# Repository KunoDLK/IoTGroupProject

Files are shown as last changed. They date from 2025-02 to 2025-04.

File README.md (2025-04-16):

# Project:

## Waste Management Optimization:

Problem: Static bin collection routes can leave many bins overflowing
Solution: Create a smart waste management system with fill-level so the council can optimes bin collection
Sensors: Ultrasonic distance sensors measure bin fill levels; Weight Sensor to approximate waste density; Air Monitoring for potential pollution cause by waste

## Work split:

Kuno:
- Hardware:
  - PCB
  - mounting + assembly
- Firmware:
  - Reading sensors
  - Sending data to cloud
- Creating Fake Data

Mark & Andrea:
- Cloud:
  - Server
- Application:
  - Collecting data from MQTT
  - displaying the data
  - Figure out which bin needs to be collected next

## The data:

- Current Data:
  - Temp
  - humidity
  - Fill Level
  - Weight
  - Density
- Daily Data:
  - Day high Temp
  - Day Low Temp
  - Day Fill delta
- Counters:
  - Time Since Emptied
  - Time Since Full
  - Number of fills
- Server Data
  - trends ect.

## MQTT:

URL:
c79e2ea5e65e40f6b79ba3a3aad7c19f.s1.eu.hivemq.cloud
Port:
8883
Websocket Port:
8884

User:admin
Password:Password1  

## MQTT Websocket Client
https://www.hivemq.com/demos/websocket-client/

## MQTT Data:

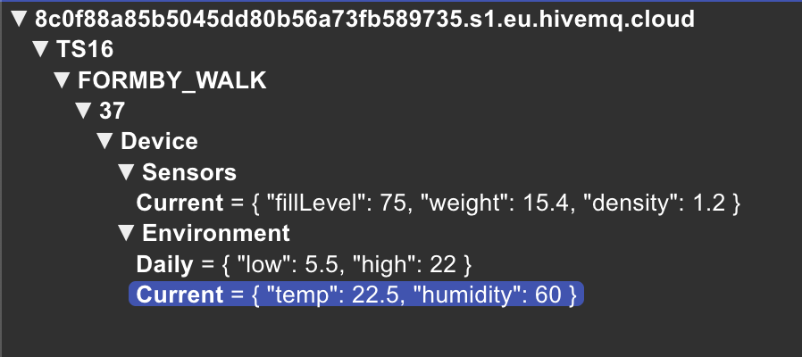
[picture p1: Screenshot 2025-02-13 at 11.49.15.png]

### Data Organisation:
{Postcode area code}/{Street Name}/{House Number}

TS16/FORMBY_WALK/01/

### Sensor Data
./Sensors/Current
{
  "fillLevel": 75,
  "weight": 15.4,
  "density": 1.2
} 

### Environment Data
./Environment/Current
{
  "temp": 22.5,
  "humidity": 60
}

./Environment/Daily
{
  "low": 5.5,
  "high" 22
}

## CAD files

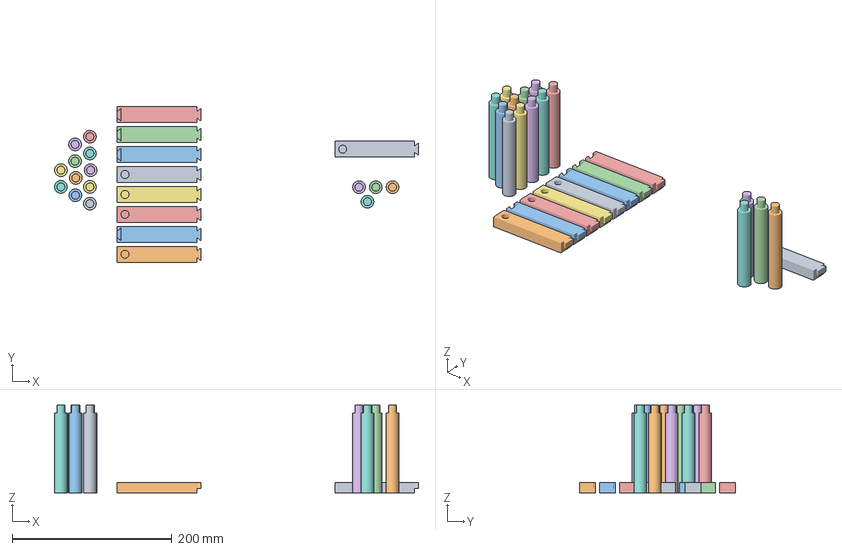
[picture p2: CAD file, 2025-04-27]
Hardware/Suport Beams/parts.3mf
456.4 x 195.0 x 110.0 mm
Straght vertical hole.step x 5
Straght dovetail.step x 4
vertical.step x 15

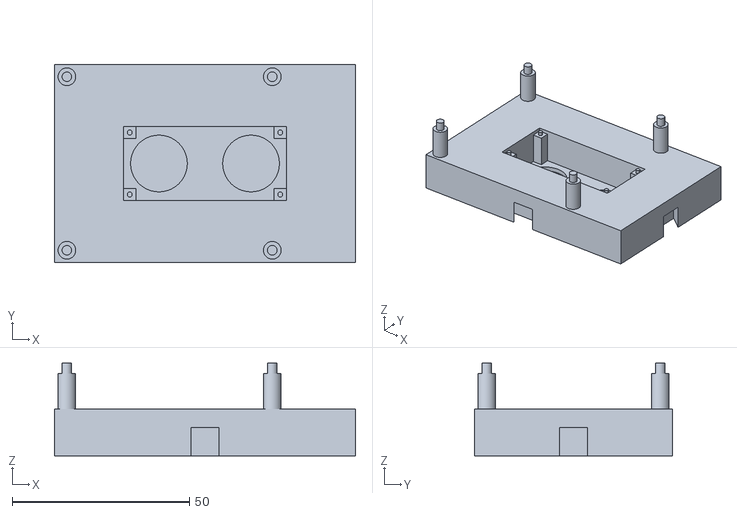
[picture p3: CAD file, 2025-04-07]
Hardware/Top Platform/TopPlatform.stl
85.0 x 56.0 x 26.2

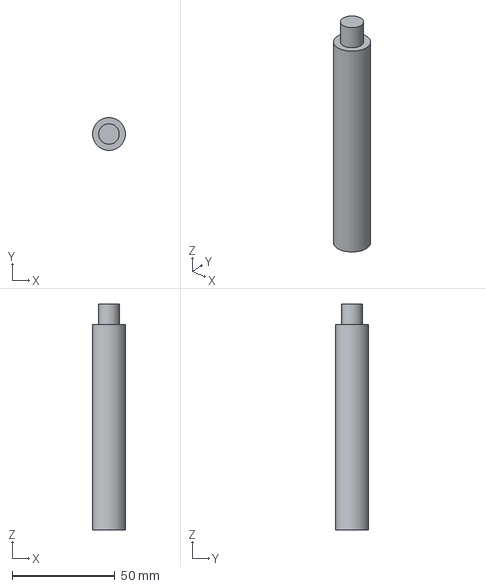
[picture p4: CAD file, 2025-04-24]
Hardware/Suport Beams/vertical.step
16.0 x 16.0 x 110.0 mm

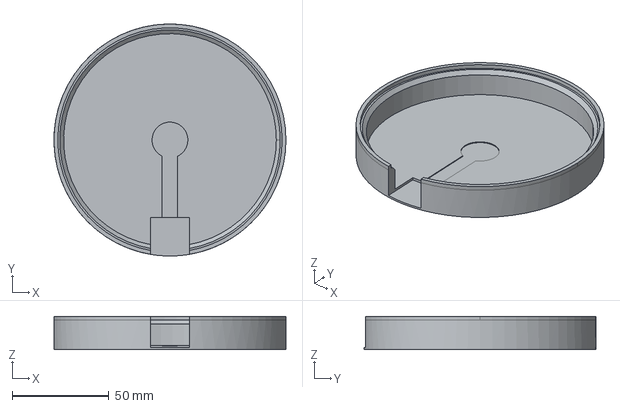
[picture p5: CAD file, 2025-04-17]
Hardware/Weight Platform/base.step
120.0 x 120.0 x 17.2 mm

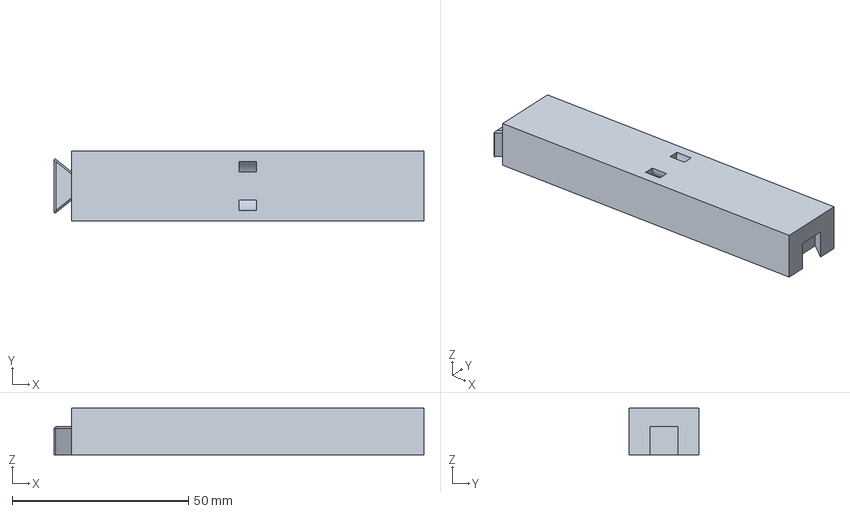
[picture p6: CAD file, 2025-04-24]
Hardware/Suport Beams/Straght.FCStd
105.0 x 20.0 x 13.2 mm

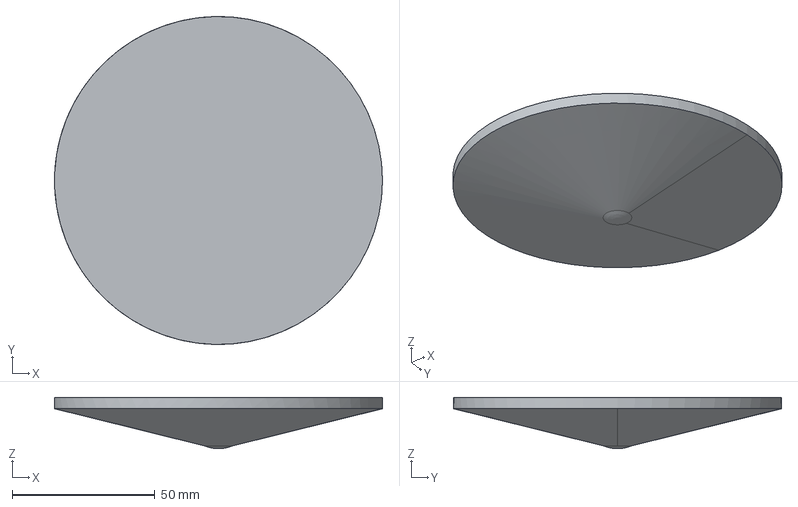
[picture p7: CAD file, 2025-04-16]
Hardware/Weight Platform/platform.step
115.0 x 115.0 x 18.0 mm

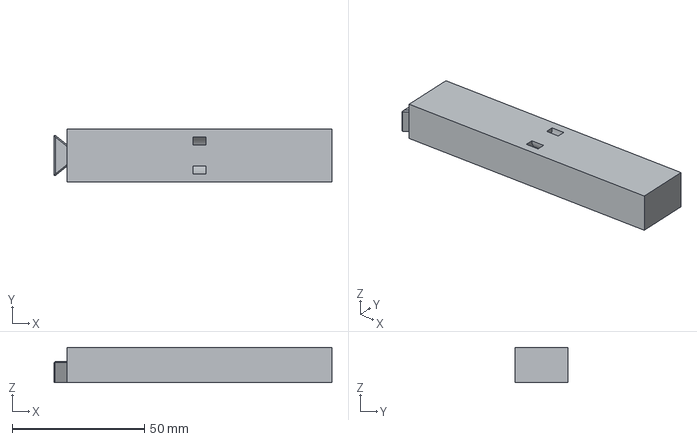
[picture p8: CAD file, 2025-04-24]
Hardware/Suport Beams/Straght vertical hole.step
105.0 x 20.0 x 13.2 mm

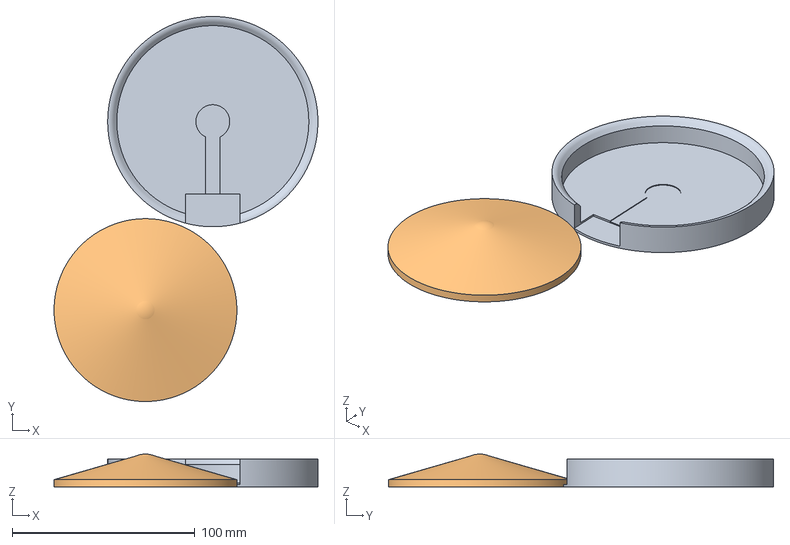
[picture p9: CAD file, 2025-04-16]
Hardware/Weight Platform/print.3mf
144.3 x 210.6 x 18.0 mm
base.step
platform.step

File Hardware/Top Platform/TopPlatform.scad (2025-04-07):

$fn = $preview ? 50 : 500;

PCB_Width = 46.0;
PCB_Depth = 1.2;
PCB_Height = 21.0;
PCB_Sonic_Height = 12.01;
PCB_Sonic_Radius = 8.0;
PCB_Sonic_Offset = 13.0;
PCB_Hole_Radius = 0.7;
PCB_Hole_X_Offset = 21.25;
PCB_Hole_Y_Offset = 8.75;

Sonic_Support_Depth = 1.5;

PI_Height = 85;
PI_Width = 56;
PI_Support_Height = 10;
PI_Support_Width = 5;
PI_Support_Offset_Y = 24.5;
PI_Support_X_Offset_1 = 19;
PI_Support_X_Offset_2 = 39;

Joint_dove_height = 8;
Joint_dove_depth = 5;
Joint_dove_rear_width = 16;
Joint_dove_front_width = 8;

showPI = false;
splitView = false;


if (splitView)
{
    intersection()
    {
        Viewer();
        
        translate([-PI_Height/2,0,0]) cube([PI_Height, PI_Width, PCB_Sonic_Height + PCB_Depth + PI_Support_Height + 3]);
    }
}
else
{
    Viewer();
}

module Viewer()
{
    if (showPI)
    {
        translate([0,0,PI_Support_Height + PCB_Depth + PCB_Sonic_Height]) RPi();
    }

    Main();
}


module Main()
{
    union()
    {
        difference()
        {
            color("Yellow") Base();
        
            rotate([180,0,0]) 
            {
                translate([0,0,-PCB_Depth - PCB_Sonic_Height]) 
                {
                    color("Red") Utrasonic();
                    color("blue")
                    {
                        cutoutLengthWidth = PCB_Height - (4 * ((PCB_Height / 2) - (PCB_Hole_Y_Offset)));
                        cutoutWidthLength = PCB_Width - (4 * ((PCB_Width / 2) - (PCB_Hole_X_Offset)));
                        
                        linear_extrude(PCB_Depth + PCB_Sonic_Height - Sonic_Support_Depth) union()
                        {
                            square([PCB_Width,cutoutLengthWidth], center = true);
                            square([cutoutWidthLength, PCB_Height], center = true);
                        }
                    }
                }
                
            }
        }
        
        translate([PI_Support_X_Offset_1,PI_Support_Offset_Y,PCB_Depth + PCB_Sonic_Height]) Support();
        translate([-PI_Support_X_Offset_2,PI_Support_Offset_Y,PCB_Depth + PCB_Sonic_Height]) Support();
        translate([PI_Support_X_Offset_1,-PI_Support_Offset_Y,PCB_Depth + PCB_Sonic_Height]) Support();
        translate([-PI_Support_X_Offset_2,-PI_Support_Offset_Y,PCB_Depth + PCB_Sonic_Height]) Support();
    }
}

module Base()
{
    render()
    {
        difference()
        {
            linear_extrude(PCB_Depth + PCB_Sonic_Height)
            {
                square([PI_Height,PI_Width], center = true);
            }
            
            linear_extrude(Joint_dove_height)
            {
                union()
                {
                    rotate([0,0,0]) translate([0, -PI_Width / 2,0]) Dovetail2d();
                    rotate([0,0,90]) translate([0, -PI_Height / 2,0]) Dovetail2d();
                    rotate([0,0,180]) translate([0, -PI_Width / 2,0]) Dovetail2d();
                    rotate([0,0,270]) translate([0, -PI_Height / 2,0]) Dovetail2d();
                }
            }
        }
    }
}

module Dovetail2d()
{
    frontOffset = Joint_dove_front_width / 2;
    rearOffset = Joint_dove_rear_width / 2;
                
    polygon([[-frontOffset,0],
    [frontOffset,0],
    [rearOffset, Joint_dove_depth],
    [-rearOffset, Joint_dove_depth]]);
}

module RPi()
{
    difference()
    {
        
        linear_extrude(1.4)
            square([PI_Height, PI_Width], center = true); 
    
        translate([-(PI_Height / 2) + 3.5,-(PI_Width / 2) + 3.5,0])
        {
            Hole();
            translate([58, 0 ,0])
            {
                Hole();
            }
        }
        translate([-(PI_Height / 2) + 3.5,+(PI_Width / 2) - 3.5,0])
        {
            Hole();
            translate([58, 0 ,0])
            {
                Hole();
            }
        }
    }
}

module Hole()
{
    cylinder(h = 3, r = 2.7 / 2);
}
   
module Support()
{
    cylinder(h =PI_Support_Height, r = PI_Support_Width / 2);
    translate([0,0,PI_Support_Height])
    {
        Hole();
    }
}

module Utrasonic() {
    
    difference()
    {
        
        union() {
            translate([-(PCB_Width / 2), -(PCB_Height / 2), 0])
            {
                cube([PCB_Width, PCB_Height, PCB_Depth]);
            }
            translate([PCB_Sonic_Offset, 0, PCB_Depth])
            {
                cylinder(h = PCB_Sonic_Height, r = PCB_Sonic_Radius);
            }
            translate([-PCB_Sonic_Offset, 0, PCB_Depth])
            {
                cylinder(h = PCB_Sonic_Height, r = PCB_Sonic_Radius);
            }
        }
        translate([PCB_Hole_X_Offset, PCB_Hole_Y_Offset, -1])
        {
            cylinder(h = PCB_Depth + 2, r = PCB_Hole_Radius);
        }
        translate([-PCB_Hole_X_Offset, PCB_Hole_Y_Offset, -1])
        {
            cylinder(h = PCB_Depth + 2, r = PCB_Hole_Radius);
        }
        translate([PCB_Hole_X_Offset, -PCB_Hole_Y_Offset, -1])
        {
            cylinder(h = PCB_Depth + 2, r = PCB_Hole_Radius);
        }
        translate([-PCB_Hole_X_Offset, -PCB_Hole_Y_Offset, -1])
        {
            cylinder(h = PCB_Depth + 2, r = PCB_Hole_Radius);
        }
    }
}

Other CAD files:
Hardware/Weight Platform/assembly.FCStd
Hardware/Suport Beams/Straght dovetail.step
Hardware/Suport Beams/Straght vertical hole.FCStd
Hardware/Suport Beams/Vertical.FCStd
Hardware/Weight Platform/base.FCStd
Hardware/Weight Platform/platform.FCStd

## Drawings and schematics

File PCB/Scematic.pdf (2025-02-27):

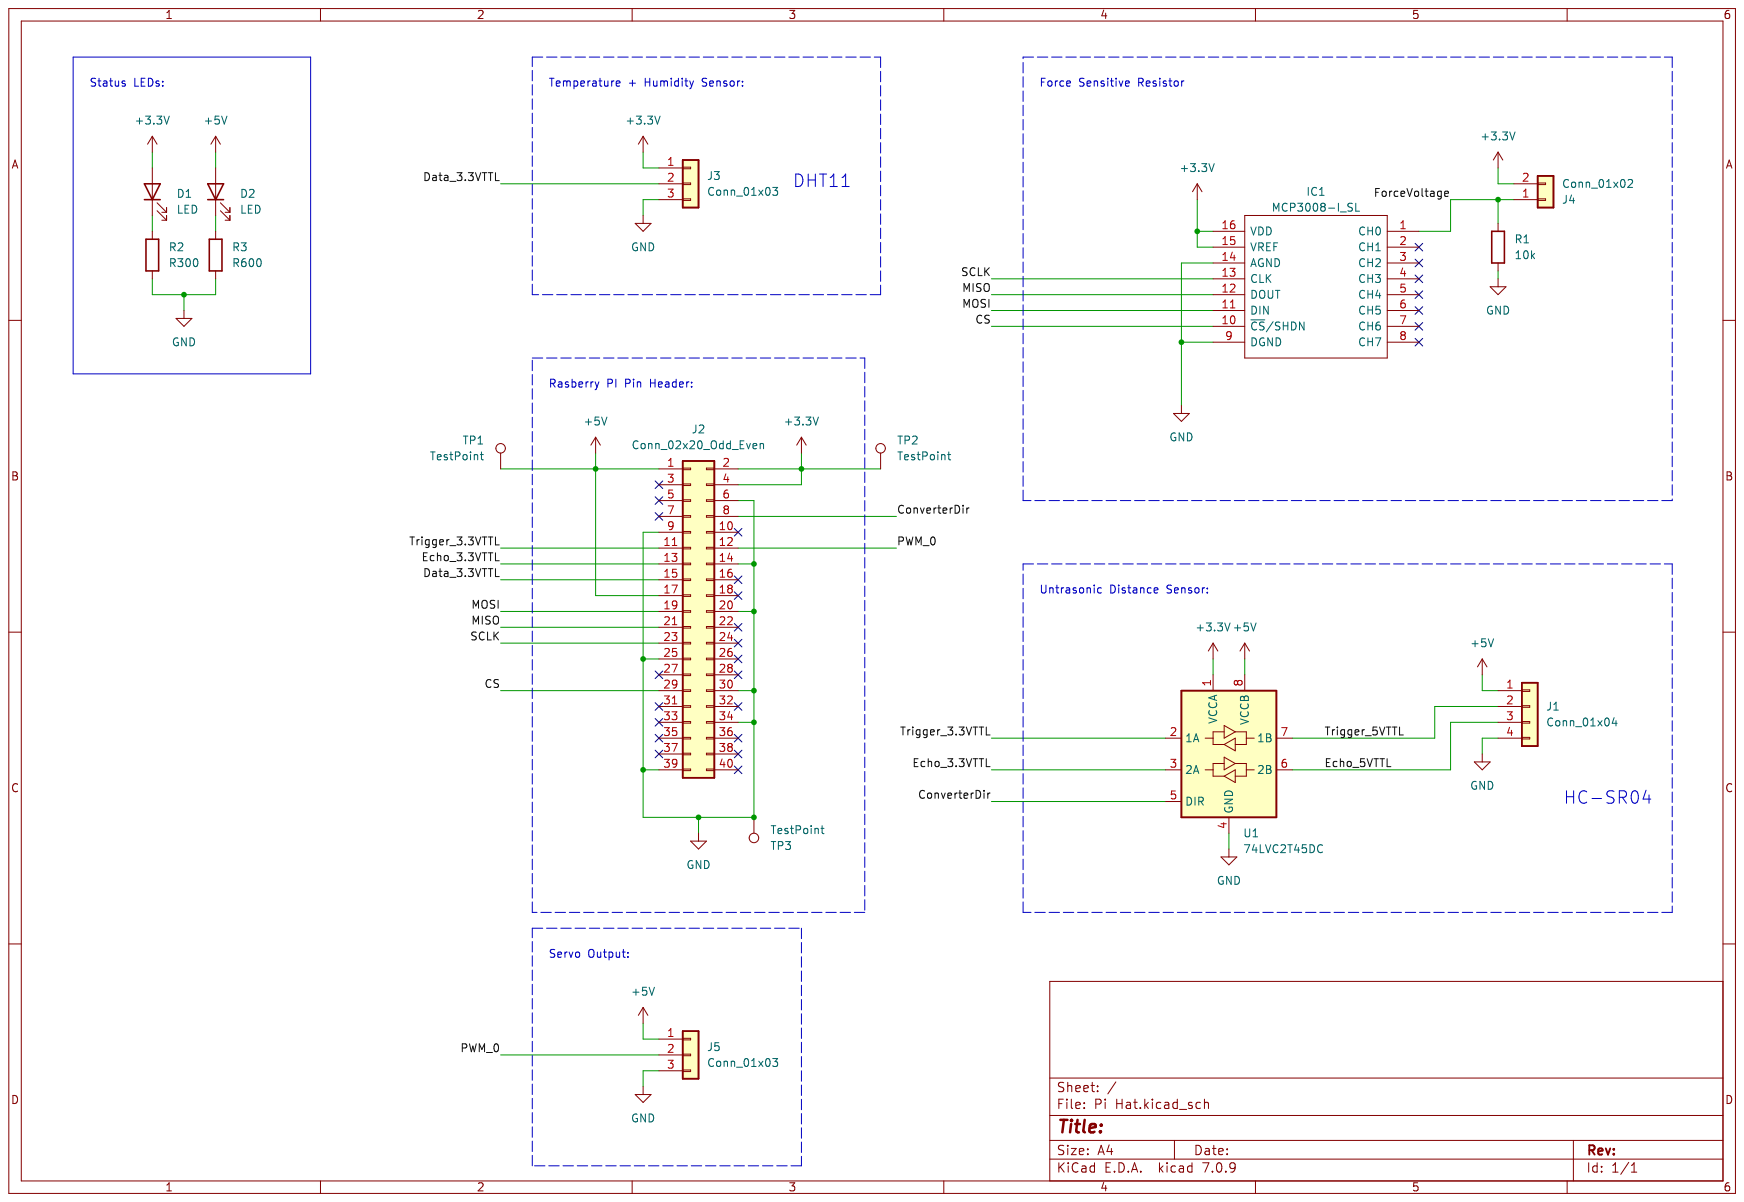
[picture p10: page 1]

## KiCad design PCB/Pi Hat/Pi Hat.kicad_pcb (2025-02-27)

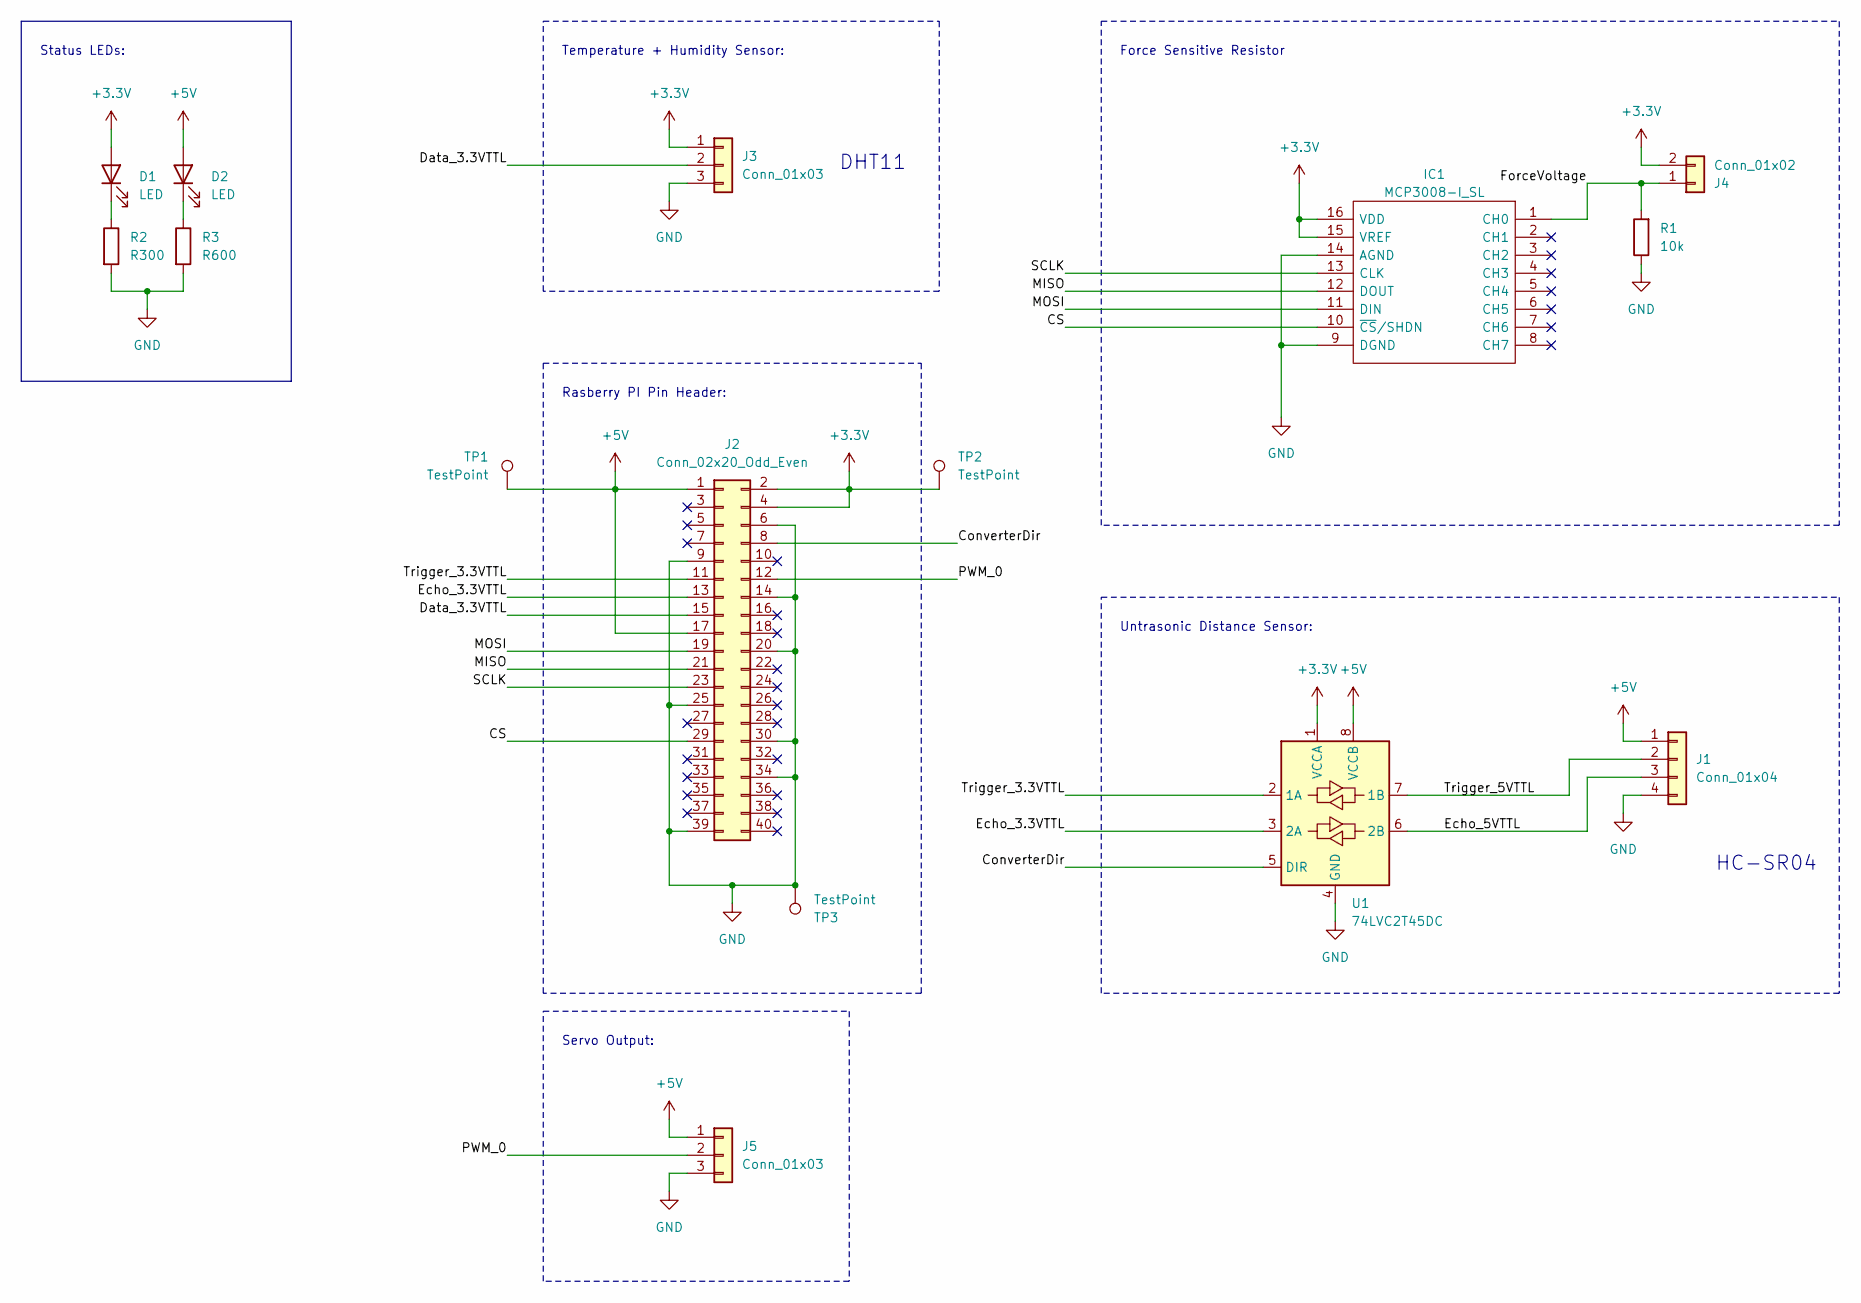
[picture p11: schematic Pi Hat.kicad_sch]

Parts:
D1, D2: LED; LED_0805_2012Metric
IC1: MCP3008-I_SL; DIP-16_W7.62mm_Socket; Manufacturer_Part_Number MCP3008-I/SL; Mouser Part Number 579-MCP3008-I/SL
J1: Conn_01x04; Molex_KK-254_AE-6410-04A_1x04_P2.54mm_Vertical
J2: Conn_02x20_Odd_Even; PinSocket_2x20_P2.54mm_Vertical
J3, J5: Conn_01x03; Molex_KK-254_AE-6410-03A_1x03_P2.54mm_Vertical
J4: Conn_01x02; Molex_KK-254_AE-6410-02A_1x02_P2.54mm_Vertical
R1: 10k; R_0805_2012Metric
R2: R300; R_0805_2012Metric
R3: R600; R_0805_2012Metric
TP1, TP2, TP3: TestPoint; TestPoint_Pad_D3.0mm
U1: 74LVC2T45DC; VSSOP-8_2.3x2mm_P0.5mm

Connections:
+3.3V: D1.2 (A), IC1.15 (VREF), IC1.16 (VDD), J2.2, J2.4, J3.1, J4.2, TP2.1, U1.1 (VCCA)
+5V: D2.2 (A), J1.1, J2.1, J2.17, J5.1, TP1.1, U1.8 (VCCB)
/CS: IC1.10 (~CS/SHDN), J2.29
/ConverterDir: J2.8, U1.5 (DIR)
/Data_3.3VTTL: J2.15, J3.2
/Echo_3.3VTTL: J2.13, U1.3 (2A)
/Echo_5VTTL: J1.3, U1.6 (2B)
/ForceVoltage: IC1.1 (CH0), J4.1, R1.2
/MISO: IC1.12 (DOUT), J2.21
/MOSI: IC1.11 (DIN), J2.19
/PWM_0: J2.12, J5.2
/SCLK: IC1.13 (CLK), J2.23
/Trigger_3.3VTTL: J2.11, U1.2 (1A)
/Trigger_5VTTL: J1.2, U1.7 (1B)
GND: IC1.9 (DGND), IC1.14 (AGND), J1.4, J2.6, J2.9, J2.14, J2.20, J2.25, J2.30, J2.34, J2.39, J3.3, J5.3, R1.1, R2.2, R3.2, TP3.1, U1.4 (GND)
unnamed: D1.1 (K), R2.1
unnamed: D2.1 (K), R3.1

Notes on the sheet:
Untrasonic Distance Sensor:
Servo Output:
Force Sensitive Resistor
Status LEDs:
DHT11
Temperature + Humidity Sensor:
Rasberry PI Pin Header:
HC-SR04

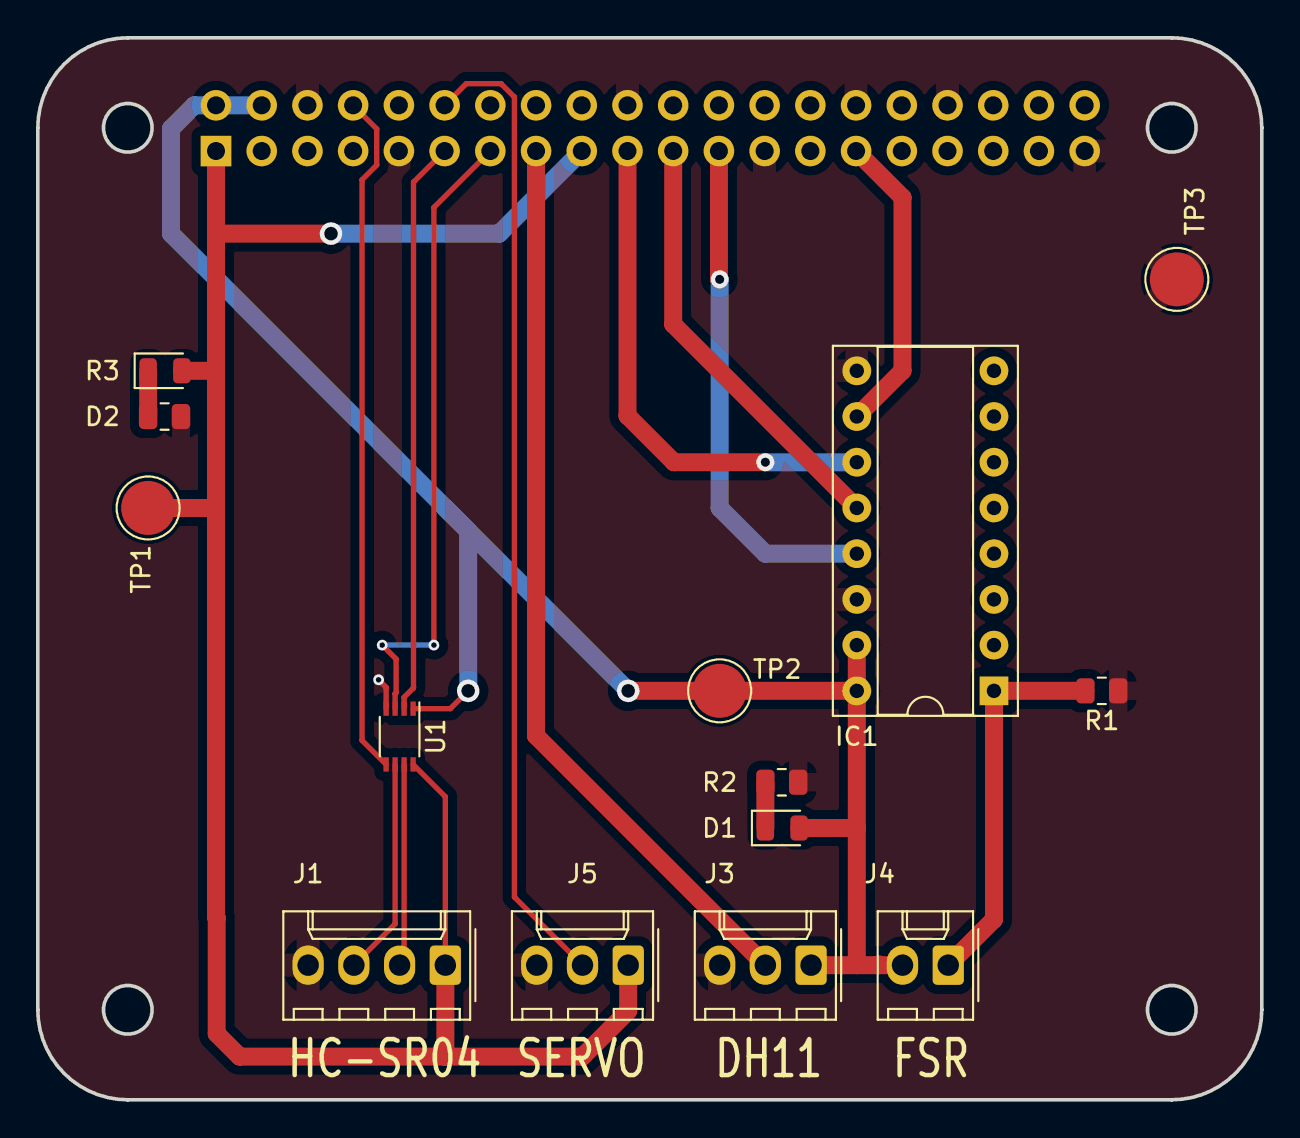
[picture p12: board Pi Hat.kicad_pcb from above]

Board: 2 copper layers, 68.0 x 59.0 mm, 15 parts (1 on the bottom side), 17 nets.

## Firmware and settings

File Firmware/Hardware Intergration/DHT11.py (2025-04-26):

#!/usr/bin/env python
# -*- coding: utf-8 -*-

from __future__ import absolute_import, division, print_function, unicode_literals

import time
import pigpio


class DHT11(object):
    """
    The DHT11 class is a stripped version of the DHT22 sensor code by joan2937.
    """

    def __init__(self, pi, gpio):
        """
        pi (pigpio): an instance of pigpio
        gpio (int): gpio pin number
        """
        self.pi = pi
        self.gpio = gpio
        self.high_tick = 0
        self.bit = 40
        self.temperature = 0
        self.humidity = 0
        self.either_edge_cb = None
        self.setup()

    def setup(self):
        """
        Clears the internal gpio pull-up/down resistor.
        Kills any watchdogs.
        """
        self.pi.set_pull_up_down(self.gpio, pigpio.PUD_OFF)
        self.pi.set_watchdog(self.gpio, 0)
        self.register_callbacks()

    def register_callbacks(self):
        """
        Monitors RISING_EDGE changes using callback.
        """
        self.either_edge_cb = self.pi.callback(
            self.gpio,
            pigpio.EITHER_EDGE,
            self.either_edge_callback
        )

    def either_edge_callback(self, gpio, level, tick):
        """
        Either Edge callbacks, called each time the gpio edge changes.
        Accumulate the 40 data bits from the dht11 sensor.
        """
        level_handlers = {
            pigpio.FALLING_EDGE: self._edge_FALL,
            pigpio.RISING_EDGE: self._edge_RISE,
            pigpio.EITHER_EDGE: self._edge_EITHER
        }
        handler = level_handlers[level]
        diff = pigpio.tickDiff(self.high_tick, tick)
        handler(tick, diff)

    def _edge_RISE(self, tick, diff):
        """
        Handle Rise signal.
        """
        val = 0
        if diff >= 50:
            val = 1
        if diff >= 200:  # Bad bit?
            self.checksum = 256  # Force bad checksum

        if self.bit >= 40:  # Message complete
            self.bit = 40
        elif self.bit >= 32:  # In checksum byte
            self.checksum = (self.checksum << 1) + val
            if self.bit == 39:
                # 40th bit received
                self.pi.set_watchdog(self.gpio, 0)
                total = self.humidity + self.temperature
                # Is checksum ok?
        elif 16 <= self.bit < 24:  # In temperature byte
            self.temperature = (self.temperature << 1) + val
        elif 0 <= self.bit < 8:  # In humidity byte
            self.humidity = (self.humidity << 1) + val
        else:
            pass  # Skip header bits
        self.bit += 1

    def _edge_FALL(self, tick, diff):
        """
        Handle Fall signal.
        """
        self.high_tick = tick
        if diff <= 250000:
            return
        # Start of new message
        self.bit = -2
        self.checksum = 0
        self.temperature = 0
        self.humidity = 0

    def _edge_EITHER(self, tick, diff):
        """
        Handle Either signal.
        """
        self.pi.set_watchdog(self.gpio, 0)

    def read(self):
        """
        Start reading over DHT11 sensor.
        """
        self.pi.write(self.gpio, pigpio.LOW)
        time.sleep(0.017)  # 17 ms
        self.pi.set_mode(self.gpio, pigpio.INPUT)
        self.pi.set_watchdog(self.gpio, 200)
        time.sleep(0.2)

    def close(self):
        """
        Stop reading sensor, remove callbacks.
        """
        self.pi.set_watchdog(self.gpio, 0)
        if self.either_edge_cb:
            self.either_edge_cb.cancel()
            self.either_edge_cb = None

    def __iter__(self):
        """
        Support the iterator protocol.
        """
        return self

    def __next__(self):
        """
        Call the read method and return temperature and humidity information.
        """
        self.read()
        response = {
            'humidity': self.humidity,
            'temperature': self.temperature
        }
        return response

    # For Python 2 compatibility (optional)
    next = __next__


# --- Test code ---

if __name__ == "__main__":
    pi = pigpio.pi()
    
    if not pi.connected:
        print("Failed to connect to pigpio daemon!")
    else:
        try:
            sensor = DHT11(pi, 4)  # GPIO4
            
            while True:
                d = next(sensor)   # Use next() explicitly or use a for loop with iter(sensor)
                print("Temperature: {}°C".format(d['temperature']))
                print("Humidity: {}%".format(d['humidity']))
                time.sleep(1)
                
        
        except KeyboardInterrupt:
            print("\nProgram stopped by user.")
        
        finally:
            sensor.close()
            pi.stop()

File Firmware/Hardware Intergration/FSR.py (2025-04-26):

import spidev

class ADCReader:
    def __init__(self, bus=0, device=0, speed=1350000):
        self.spi = spidev.SpiDev()
        self.spi.open(bus, device)
        self.spi.max_speed_hz = speed

    def read_channel(self, channel):
        if not 0 <= channel <= 7:
            return -1
        adc = self.spi.xfer2([1, (8 + channel) << 4, 0])
        value = ((adc[1] & 3) << 8) + adc[2]
        return value

    def close(self):
        self.spi.close()


import time
import math

weightReader = ADCReader()
lastPrintedWeight = -100.0
lastPrintTime = time.time()

try:
    while True:
        adc_value = weightReader.read_channel(0)
        voltage = (adc_value / 1024.0) * 5.0  # Convert ADC count to voltage
        weight =  0.2 * math.exp(voltage)   # Since a=1 and b=1, F = e^(V)

        currentTime = time.time()
        
        if abs(weight - lastPrintedWeight) > 1:
            print("Weight: {:.2f}KG".format(weight))
            lastPrintedWeight = weight
            lastPrintTime = currentTime
        elif currentTime - lastPrintTime >= 0.5:
            print("Weight: {:.2f}KG".format(weight))
            lastPrintedWeight = weight
            lastPrintTime = currentTime

        time.sleep(0.05)  # 10ms

except KeyboardInterrupt:
    print("\nProgram stopped by user.")

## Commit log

2025-01-30 Added example code for temp/humid Sensor DH11
2025-01-30 Added PI Hat PCB
    [Pi Hat.kicad_pcb, Pi Hat.kicad_sch]
2025-01-30 completed PCB
    [Pi Hat.kicad_pcb, Pi Hat.kicad_sch]
2025-01-30 Experted fabrication files
    [Pi Hat-B_Cu.gbr, Pi Hat-B_Mask.gbr, Pi Hat-B_Silkscreen.gbr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]
2025-01-30 updated PCB
    [Pi Hat.kicad_pcb]
2025-02-03 added 3d design files
    [BinPOC.scad, BinPOC.stl]
2025-02-03 completed placement of ultrasonic sensor
    [BinPOC.scad]
2025-02-04 completed mounting for PI
    [BinPOC.scad, BinPOC.stl]
2025-02-27 complete PCB
    [BinPOC.scad, BinPOC.stl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]
2025-02-27 DFM check adjustments
    [Pi Hat-B_Cu.gbr, Pi Hat-B_Mask.gbr, Pi Hat-B_Silkscreen.gbr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]
2025-04-03 restructured binPOC model. smaller platform with dovetail joints
    [BinPOC.scad]
2025-04-03 Updated model
    [BinPOC.stl]
2025-04-03 adjusted dovetail joints for strength
    [BinPOC.scad, BinPOC.stl]
2025-04-06 made adjustments to pi holder for better sonic fitment
    [BinPOC.scad]
2025-04-06 exported binPOC stl
    [BinPOC.stl]
2025-04-06 changed file name
    [TopPlatform.scad, TopPlatform.stl]
2025-04-06 renamed top platform
    [TopPlatform.scad, TopPlatform.stl]
2025-04-06 created FSR base support
    [WeightPlatform.scad]
2025-04-06 exported STL
    [WeightPlatform.stl]
2025-04-07 update design parameters for fitment
    [TopPlatform.scad, TopPlatform.stl]
2025-04-15 added straight beam
    [Straght.FCStd]
2025-04-15 completed weight platform
    [Straght.FCStd, WeightPlatform.scad, WeightPlatform.stl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]
2025-04-16 updated dimensions
    [assembly.FCStd, base.FCStd, base.step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]
2025-04-16 updated print file
    [print.3mf]
2025-04-16 exported platform
    [assembly.FCStd, platform.step]
2025-04-17 ML script to predict bin collection
    ML script to predict bin collection
    [mock_bin_data.csv]
2025-04-17 added rim around weight platform base
    [assembly.FCStd, base.FCStd, base.step]
2025-04-22 completed support beams
    [Straght dovetail.step, Straght vertical hole.FCStd, Straght vertical hole.step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]
2025-04-23 added mock implemetations for sensors
2025-04-23 change voltage scaler
2025-04-23 added ADC reading to MQTT loop
2025-04-24 updated support beams
    [Straght dovetail.step, Straght vertical hole.FCStd, Straght vertical hole.step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]
2025-04-26 completed firmware. all sensors working + mqtt intergration
2025-04-27 updated 3d print file
    [parts.3mf]
2025-04-27 changed sleep time between sending sensor data
